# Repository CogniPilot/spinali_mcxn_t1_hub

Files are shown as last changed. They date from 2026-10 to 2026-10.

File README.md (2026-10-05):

# MR-MCXN-T1 Hub

> [!NOTE]
> An MCXN947 based multi-purpose base board with a modular board-to-board connector interface. 
> The base board is supplied with the following features:
> - 3S-12S supply voltage
> - 100BASE-T1 Ethernet
> - 2x CAN
> - IMU (TDK InvenSense ICM-45686)
> - Magnetometer (Bosch BMM350)
> - Barometer (Bosch BMP581)
> - USB
> - 10-pin debug connector (Pixhawk standard)
> - Addressable RGB LED

> [!TIP]
> Possible use-cases for add-on boards:
> Camera, Microphone, Audio, SDIO, Mikrobus, Display, ADC, IO
>
> Please see the associated add-on boards [here](https://github.com/CogniPilot/spinali_mcxn_t1_shields).

MR-MCXN-T1 Top view  |  MR-MCXN-T1 Bottom view
:-------------------------:|:-------------------------:
IMG_8519_cropped | IMG_8513_cropped

> [!NOTE]
> Designed with KiCAD
> 
> All JST-GH connector pinouts follows the [DS-009 Connector Standard](https://github.com/pixhawk/Pixhawk-Standards/blob/master/DS-009%20Pixhawk%20Connector%20Standard.pdf).

> [!NOTE]
> If desiring to contribute please open [all PRs here](https://github.com/CogniPilot/spinali_mcxn_t1_hub/pulls).

## Board overview

All pin data below comes from the KiCad design files in this repository.

Each card shows, per pin, the **function**, the **net name in the schematic** and the **MCU pad**
the signal ends up on. Parts in between, such as the CAN transceivers and the Ethernet PHY, are
shown too. Pin 1 is the square pad.

<!-- overview:top -->
<picture>
  <source media="(prefers-color-scheme: dark)" srcset="images/overview-top-dark.svg">
  MR-MCXN-T1 Hub top view with connector labels
</picture>
<!-- /overview -->

<!-- overview-list:top -->
Bottom side: [J1 VIN + T1](#hub-j1-vin--t1) · [J2 USB](#hub-other-connectors) · [J5 DEBUG](#hub-j5-debug) · [J13 RTC_BAT](#hub-j13-rtc_bat) · [SW1 ISP](#buttons-and-switches).
<!-- /overview-list -->

Bottom side, with the power and Ethernet connector, USB, debug port and the bottom CAN connectors:

<!-- overview:bottom -->
<picture>
  <source media="(prefers-color-scheme: dark)" srcset="images/overview-bottom-dark.svg">
  MR-MCXN-T1 Hub bottom view with connector labels
</picture>
<!-- /overview -->

<!-- overview-list:bottom -->
New in the current revision, bottom right corner (the photo shows the old revision): [J13 RTC_BAT](#hub-j13-rtc_bat).
<!-- /overview-list -->

## Connector index

<!-- index -->
| Ref | Function | Connector | Details |
|---|---|---|---|
| [Hub J1](#hub-j1-vin--t1) VIN + T1 | Battery input 3S to 12S and 100BASE-T1 Ethernet on one cable | Molex Micro-Lock Plus 1x4 (505578-0421), 1.25 mm, side entry |  |
| [Hub J2](#hub-other-connectors) USB | USB 2.0 high-speed device port | USB Type-C receptacle (USB4105-GF-A) | On USB1 of the MCXN947 (high speed). The board is always a USB device (CC pull-downs). VBUS powers the board through load switch U2 when no battery is connected. With SW1 held at power up the boot ROM listens here for ISP programming. |
| [Hub J3](#hub-j3-can0) CAN0 | CAN FD bus 0 (TJA1462), two connectors in parallel | JST-GH 1x4, J3 on the bottom side and J4 on the top side |  |
| [Hub J5](#hub-j5-debug) DEBUG | SWD, JTAG and console, DS-009 debug full layout | JST-SH 1x10 |  |
| [Hub J6](#hub-j6-can1) CAN1 | CAN FD bus 1 (TJA1462), two connectors in parallel | JST-GH 1x4, J6 on the bottom side and J7 on the top side |  |
| [Hub J8](#hub-j8-b2b-power--io) B2B POWER + IO | Add-on board connector 1: power rails and FlexComm, I3C, analog and trace pins | Hirose DF40 50-pin header, 0.4 mm pitch, 3.0 mm stack (DF40TC(3.0)-50DP-0.4V) |  |
| [Hub J9](#hub-j9-b2b-sdhc--io) B2B SDHC + IO | Add-on board connector 2: SDHC or FlexComm 9, SmartDMA or FlexComm 6/7, and more FlexComm pins | Hirose DF40 50-pin header, 0.4 mm pitch, 3.0 mm stack (DF40TC(3.0)-50DP-0.4V) |  |
| [Hub J13](#hub-j13-rtc_bat) RTC_BAT | Backup battery for the RTC | JST-SH 1x2, side entry |  |
| [Hub RGB](#hub-rgb-led-chain) LED CHAIN | Output of the on-board RGB LED, solder pads | Three pads marked CKO, SDO and G next to U14, 5 V logic |  |
<!-- /index -->

## Power, Ethernet and USB

<!-- heading:main/J1 -->
### Hub J1 VIN + T1
<!-- /heading -->

<!-- pinout:main/J1 -->
<picture>
  <source media="(prefers-color-scheme: dark)" srcset="images/main-J1-dark.svg">
  Hub J1 VIN + T1 pinout
</picture>

Pin 1 takes the battery, 3S to 12S (about 9 to 50 V), 10 W budget. An ideal diode (LM74700) blocks reverse polarity, a buck converter makes 5 V from it, and 3.3 V and 1.8 V come from the 5 V rail. The 5 V rail switches on above about 8 V. Pins 2 and 3 are the 100BASE-T1 pair, one twisted pair to the TJA1103 PHY. The PHY is the link slave (R41 fitted); remove R41 to make it the master. The other end of the T1 link must be the master. Mating parts from the schematic: socket 505570-0401, crimp 505572-1100, pre-crimped wires 217500-1125 (black) and 217500-2125 (red).

> [!CAUTION]
> Pin 1 is the only power input besides USB. Keep the battery above 3S, the board does not start below about 8 V.
<!-- /pinout -->

## CAN

<!-- heading:main/J3 -->
### Hub J3 CAN0
<!-- /heading -->

<!-- pinout:main/J3 -->
<picture>
  <source media="(prefers-color-scheme: dark)" srcset="images/main-J3-dark.svg">
  Hub J3 CAN0 pinout
</picture>

J3 (bottom) and J4 (top) carry the same bus, so one cable can come in and another go out. The transceiver runs from 5 V and talks to the chip at 3.3 V. Drive P4_14 (CAN0_STB) low to enable it. The split termination (R27, R28 and C70) is not fitted, so the bus must be terminated elsewhere, or fit the parts if the hub is one end of the bus.

> [!NOTE]
> Pin 1 is not powered. It is only linked between J3 and J4, so a 5 V supply on one cable passes to the other.
<!-- /pinout -->

<!-- heading:main/J6 -->
### Hub J6 CAN1
<!-- /heading -->

<!-- pinout:main/J6 -->
<picture>
  <source media="(prefers-color-scheme: dark)" srcset="images/main-J6-dark.svg">
  Hub J6 CAN1 pinout
</picture>

Same circuit as CAN0. J6 (bottom) and J7 (top) carry the same bus. Drive P4_17 (CAN1_STB) low to enable the transceiver. The split termination (R30, R31 and C75) is not fitted.

> [!NOTE]
> Pin 1 is not powered. It is only linked between J6 and J7, so a 5 V supply on one cable passes to the other.
<!-- /pinout -->

## Debug

<!-- heading:main/J5 -->
### Hub J5 DEBUG
<!-- /heading -->

<!-- pinout:main/J5 -->
<picture>
  <source media="(prefers-color-scheme: dark)" srcset="images/main-J5-dark.svg">
  Hub J5 DEBUG pinout
</picture>

Pin 1 is a 3.3 V reference output for the probe. Pins 2 and 3 are FlexComm 1 as a UART console. Pins 4 to 7 are the SWD and JTAG lines of the MCXN947, pin 8 is a spare GPIO for the probe, pin 9 is the chip reset, pulled up on the board.

> [!WARNING]
> Pin 1 is a reference output, not a supply input. Never power the board from it.
<!-- /pinout -->

## Board-to-board interface

<!-- heading:main/J8 -->
### Hub J8 B2B POWER + IO
<!-- /heading -->

<!-- pinout:main/J8 -->
<picture>
  <source media="(prefers-color-scheme: dark)" srcset="images/main-J8-dark.svg">
  Hub J8 B2B POWER + IO pinout
</picture>

Together with J9 this is the interface for the add-on boards (camera, audio, SDIO, mikroBUS, display, ADC, IO). Odd pins are one row, even pins the other, pin 1 at the cut corner. Limits from the schematic: 300 mA per pin, 5 V rail 1 A, 3.3 V rail 500 mA, 1.8 V rail 200 mA. Pin 11 is the RTC backup supply, shared with J13. The FlexComm blocks (FC2, FC4, FC6) can each be a UART, SPI or I2C. The grey chips list the other functions of each pad.

> [!TIP]
> The add-on board designs are in the spinali_mcxn_t1_shields repository, linked from the main README.
<!-- /pinout -->

<!-- heading:main/J9 -->
### Hub J9 B2B SDHC + IO
<!-- /heading -->

<!-- pinout:main/J9 -->
<picture>
  <source media="(prefers-color-scheme: dark)" srcset="images/main-J9-dark.svg">
  Hub J9 B2B SDHC + IO pinout
</picture>

Second add-on connector. No power pins here, all supplies are on J8. Every signal pin has more than one job, that is the point of this interface. The SDHC0 pins carry an 8-bit SD or eMMC interface, but the same pads are FlexComm 9 (P0 to P6), so an add-on board can use them as one more UART, SPI or I2C instead. The SmartDMA pins are a parallel camera port and double as FlexComm 6 and 7 lines or PWM0 outputs. FC0, FC3 and FC7 can each be a UART, SPI or I2C. Pin 44 is also the IMU sync input. The grey chips list the other functions of each pad.
<!-- /pinout -->

## LED chain and RTC battery

<!-- heading:main/RGB -->
### Hub RGB LED CHAIN
<!-- /heading -->

<!-- pinout:main/RGB -->
<picture>
  <source media="(prefers-color-scheme: dark)" srcset="images/main-RGB-dark.svg">
  Hub RGB LED CHAIN pinout
</picture>

The MCU drives one SK9822 RGB LED (U14, APA102 compatible) from FlexIO pins P0_8 (data) and P0_9 (clock). CKO and SDO are the clock and data outputs of that LED, so more LEDs of the same type can be chained from here. The LED runs from 5 V, so its outputs are 5 V.
<!-- /pinout -->

<!-- heading:main/J13 -->
### Hub J13 RTC_BAT
<!-- /heading -->

<!-- pinout:main/J13 -->
<picture>
  <source media="(prefers-color-scheme: dark)" srcset="images/main-J13-dark.svg">
  Hub J13 RTC_BAT pinout
</picture>

Keeps the real-time clock of the MCXN947 running without main power. Fits the RPi RTC battery (ML2020 with a 2-pin JST-SH plug). The same supply is on J8 pin 11 for the add-on board. The board charges the cell from 3.3 V through D15 and a 75 Ω resistor.

> [!WARNING]
> The board trickle-charges this cell. Use a rechargeable ML2020 type, never a CR2032 or other non-rechargeable cell.
<!-- /pinout -->

<!-- others:main -->
### Hub other connectors

| Ref | Function | Connector | Notes |
|---|---|---|---|
| J2 USB | USB 2.0 high-speed device port | USB Type-C receptacle (USB4105-GF-A) | On USB1 of the MCXN947 (high speed). The board is always a USB device (CC pull-downs). VBUS powers the board through load switch U2 when no battery is connected. With SW1 held at power up the boot ROM listens here for ISP programming. |
<!-- /others -->

## Buttons and switches

<!-- switches -->
| Ref | Board | Function | Type | Notes |
|---|---|---|---|---|
| SW1 ISP | Hub | ISP boot button | Tactile switch, bottom side | Hold it while power comes up to start the boot ROM in ISP mode (P0_6 ISPMODE_N pulled low), for programming over USB or the debug UART. Normal boot otherwise. |
<!-- /switches -->

## On-board devices

How the sensors, the PHY and the LED are wired to the MCXN947. Useful for a device tree or
board file.

| Device | Bus | MCU pins | Notes |
|---|---|---|---|
| ICM-45686 IMU (U9) | SPI on FlexComm 8 | SCK P3_15, MOSI P3_14, MISO P3_16, CS P3_17, INT1 P3_22, FSYNC/INT2 P0_18 | P0_18 is also on J9 pin 44 as IMU sync. |
| BMM350 magnetometer (U10) | I3C0 (or I2C) | SDA P0_20, SCL P0_21, INT P0_19 | Address 0x14. Runs from 1.8 V. |
| BMP581 barometer (U11) | I3C0 (or I2C) | SDA P0_20, SCL P0_21, INT P0_11 | Address 0x47 (SDO pulled up, R48 not fitted). |
| TJA1103 100BASE-T1 PHY (U15) | RMII on ENET0 | TXD0 P1_6, TXD1 P1_7, TXEN P1_5, TXER P1_10, RXD0 P1_14, RXD1 P1_15, RXDV P1_13, RXER P1_12, REFCLK P1_4, MDC P1_20, MDIO P1_21, INT P1_19, RESET P1_11, WAKE P0_31 | Reverse RMII: the PHY supplies the 50 MHz reference clock. PHY address 18. Link slave, because R41 is fitted; remove R41 for master. The two LEDs next to J1 are driven by the PHY GPIO0 and GPIO1. |
| TJA1462 CAN FD transceivers (U12, U13) | FlexCAN0, FlexCAN1 | CAN0 TX P4_13, RX P4_12, STB P4_14; CAN1 TX P4_16, RX P4_15, STB P4_17 | Drive STB low to enable a transceiver. |
| SK9822 RGB LED (U14) | FlexIO | data P0_8, clock P0_9 | APA102 compatible, 5 V. Chain output on the CKO, SDO and G pads. |
| ISP button (SW1) | GPIO | P0_6 | ISPMODE_N, boot ROM ISP mode when held at power up. |

Test pads on the bottom side: CLK is the PHY reference clock (P1_4), GND is ground.

## Notes

- The JST-GH and JST-SH connectors follow the Dronecode
  [DS-009 connector standard](https://github.com/pixhawk/Pixhawk-Standards/blob/master/DS-009%20Pixhawk%20Connector%20Standard.pdf)
  (CAN and debug full), so standard cables fit. The CAN pin 1 is not powered on this board, and
  the CAN termination resistors are not fitted.
- The board runs from the battery on J1 or from USB. 5 V, 3.3 V and 1.8 V for an add-on board
  come from J8.
- The photos show the old revision, marked X-MR-MCXN-T1. The RTC battery connector J13 was
  added in the current revision, in the bottom right corner of the bottom side.

> [!WARNING]
> Never feed power into the 5 V, 3.3 V or 1.8 V pins of J8, or into pin 1 of the debug port. Power the board through J1 or USB only.

## Downloads

This reference as an [A4 PDF](MR-MCXN-T1-Hub-hardware-reference.pdf), and all cards on one
A4 landscape sheet: [cheat sheet PDF](MR-MCXN-T1-Hub-cheatsheet.pdf).

NXP and the NXP logo are registered trademarks of NXP B.V. This document is maintained by the
community and is not an official NXP publication.

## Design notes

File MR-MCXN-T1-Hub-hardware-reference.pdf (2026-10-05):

# MR-MCXN-T1 Hub hardware reference

# Board overview

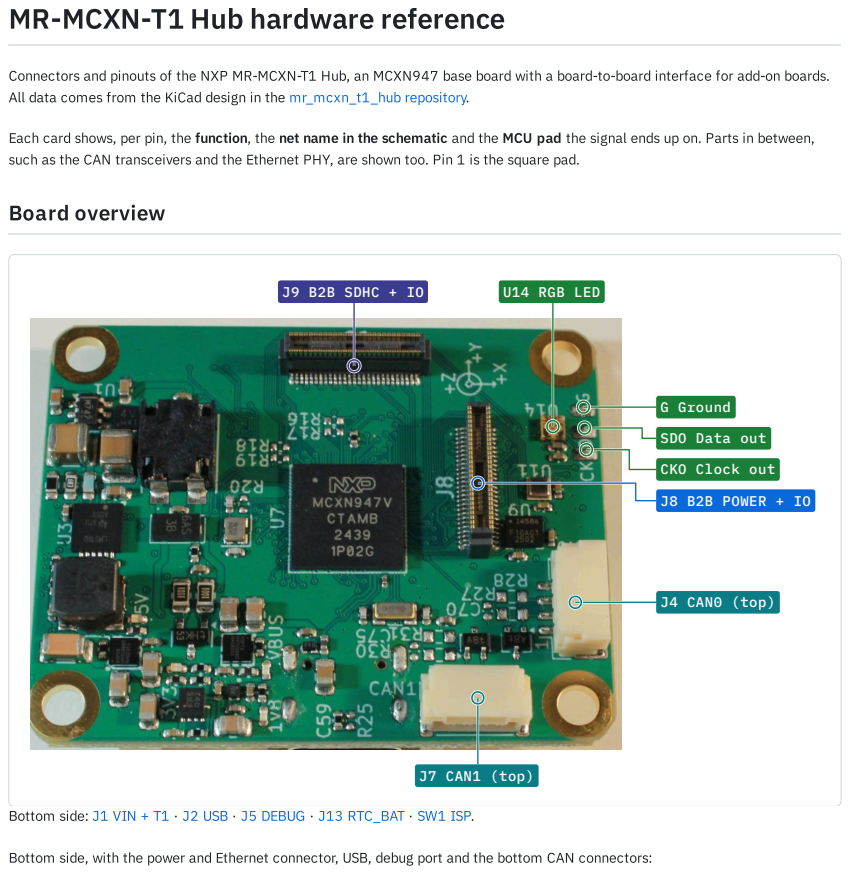
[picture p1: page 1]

Connectors and pinouts of the NXP MR-MCXN-T1 Hub, an MCXN947 base board with a board-to-board interface for add-on boards.

All data comes from the KiCad design in the mr_mcxn_t1_hub repository. (https://github.com/NXP-Robotics/mr_mcxn_t1_hub)

Each card shows, per pin, the function, the net name in the schematic and the MCU pad the signal ends up on. Parts in between,

such as the CAN transceivers and the Ethernet PHY, are shown too. Pin 1 is the square pad.

Bottom side: J1 VIN + T1 · J2 USB · J5 DEBUG · J13 RTC_BAT · SW1 ISP.

Bottom side, with the power and Ethernet connector, USB, debug port and the bottom CAN connectors:

## J3 CAN0 (bottom)

J1 VIN + T1 | J2 USB | J6 CAN1 (bottom)

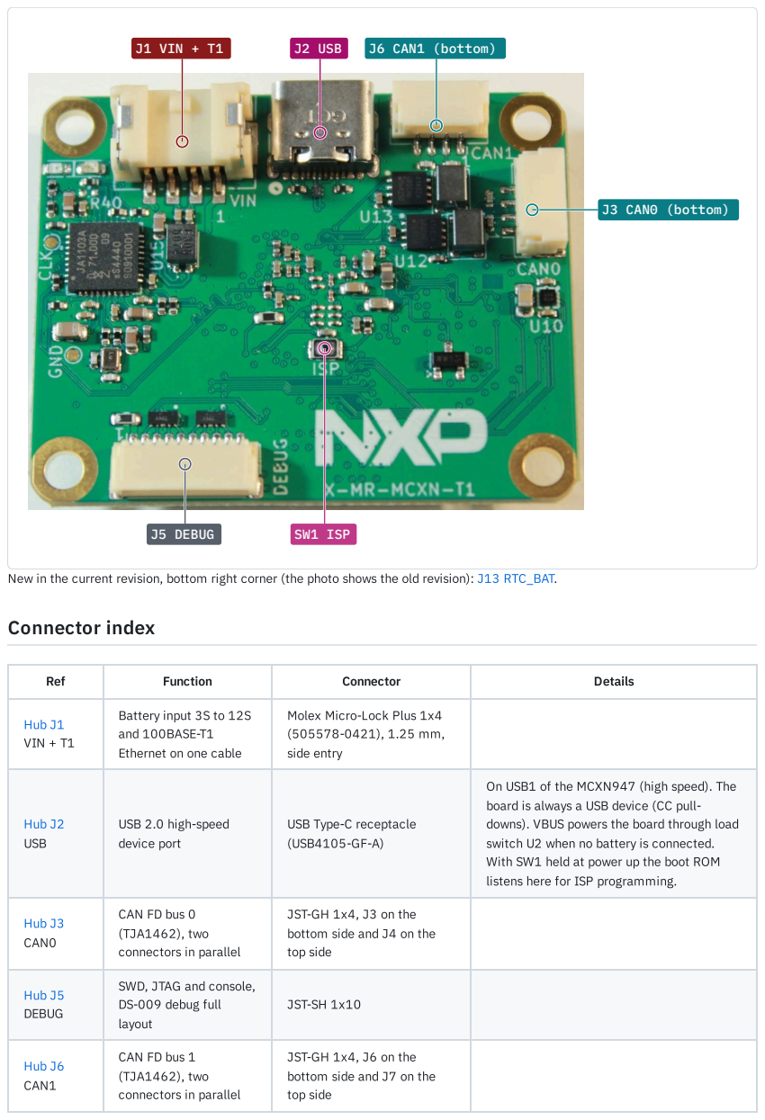
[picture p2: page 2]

New in the current revision, bottom right corner (the photo shows the old revision): J13 RTC_BAT.

Ref | Function | Connector | Details

Hub J1 VIN + T1 | Battery input 3S to 12S and 100BASE-T1 Ethernet on one cable | Molex Micro-Lock Plus 1x4 (505578-0421), 1.25 mm, side entry

Hub J2 USB | USB 2.0 high-speed device port | USB Type-C receptacle (USB4105-GF-A) | On USB1 of the MCXN947 (high speed). The board is always a USB device (CC pull-downs). VBUS powers the board through load switch U2 when no battery is connected. With SW1 held at power up the boot ROM listens here for ISP programming.

Hub J3 CAN0 | CAN FD bus 0 (TJA1462), two connectors in parallel | JST-GH 1x4, J3 on the bottom side and J4 on the top side

Hub J5 DEBUG | SWD, JTAG and console, DS-009 debug full layout | JST-SH 1x10

Hub J6 CAN1 | CAN FD bus 1 (TJA1462), two connectors in parallel | JST-GH 1x4, J6 on the bottom side and J7 on the top side

Ref | Function | Connector | Details
Hub J8 B2B POWER + IO | Add-on board connector 1: power rails and FlexComm, I3C, analog and trace pins | Hirose DF40 50-pin header, 0.4 mm pitch, 3.0 mm stack (DF40TC(3.0)-50DP-0.4V)
Hub J9 B2B SDHC + IO | Add-on board connector 2: SDHC or FlexComm 9, SmartDMA or FlexComm 6/7, and more FlexComm pins | Hirose DF40 50-pin header, 0.4 mm pitch, 3.0 mm stack (DF40TC(3.0)-50DP-0.4V)
Hub J13 RTC_BAT | Backup battery for the RTC | JST-SH 1x2, side entry
Hub RGB LED CHAIN | Output of the on-board RGB LED, solder pads | Three pads marked CKO, SDO and G next to U14, 5 V logic

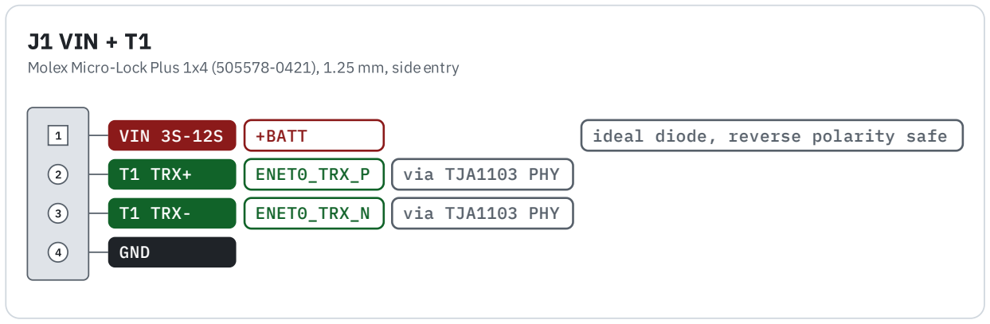
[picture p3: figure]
J1 VIN + T1; T1 TRX+; ENET0_TRX_P; via TJA1103 PHY; T1 TRX-; ENET0_TRX_N; GND

Molex Micro-Lock Plus 1x4 (505578-0421), 1.25 mm, sideentry

1 | VIN 3S-12S | +BATT | ideal diode, reverse polarity safe

Pin 1 takes the battery, 3S to 12S (about 9 to 50 V), 10 W budget. An ideal diode (LM74700) blocks reverse polarity, a buck

converter makes 5 V from it, and 3.3 V and 1.8 V come from the 5 V rail. The 5 V rail switches on above about 8 V. Pins 2 and 3 are

the 100BASE-T1 pair, one twisted pair to the TJA1103 PHY. The PHY is the link slave (R41 fitted); remove R41 to make it the

master. The other end of the T1 link must be the master. Mating parts from the schematic: socket 505570-0401, crimp 505572-

1100, pre-crimped wires 217500-1125 (black) and 217500-2125 (red).

### Caution

Pin 1 is the only power input besides USB. Keep the battery above 3S, the board does not start below about 8 V.

# Power, Ethernet and USB

### Hub J1 VIN + T1

## J3 CAN0

JST-GH 1x4, J3 on the bottom side and J4 on the top side · DS-009 CAN

120 Ω termination: not fitted

TJA1462

CAN FD transceiver

CANH | TXD | CAN0 TX | P4_13
CANL | RXD | CAN0 RX | P4_12
1 | 5V pass-through | NC | J3.1 to J4.1 only
2 | CAN H | CAN0_CONN_P
3 | CAN L | CAN0_CONN_N
4 | GND

J3 (bottom) and J4 (top) carry the same bus, so one cable can come in and another go out. The transceiver runs from 5 V and talks

to the chip at 3.3 V. Drive P4_14 (CAN0_STB) low to enable it. The split termination (R27, R28 and C70) is not fitted, so the bus

must be terminated elsewhere, or fit the parts if the hub is one end of the bus.

### Note

Pin 1 is not powered. It is only linked between J3 and J4, so a 5 V supply on one cable passes to the other.

## J6 CAN1

JST-GH 1x4, J6 on the bottom side and J7 on the top side · DS-009 CAN

120 Ω termination: not fitted

TJA1462

CAN FD transceiver

CANH | TXD | CAN1 TX | P4_16
CANL | RXD | CAN1 RX | P4_15
1 | 5V pass-through | NC | J6.1 to J7.1 only
2 | CAN H | CAN1_CONN_P
3 | CAN L | CAN1_CONN_N
4 | GND

Same circuit as CAN0. J6 (bottom) and J7 (top) carry the same bus. Drive P4_17 (CAN1_STB) low to enable the transceiver. The

split termination (R30, R31 and C75) is not fitted.

### Note

Pin 1 is not powered. It is only linked between J6 and J7, so a 5 V supply on one cable passes to the other.

# CAN

### Hub J3 CAN0

### Hub J6 CAN1

J5 DEBUG

JST-SH 1x10 · DS-009 debug full · 3.3 V logic

1 | VREF 3.3V | +3.3V
2 | UART TX | FC1_P1_UART_TXD | FC1_P1 | CT0_MAT1 | ADC0_B17 | P0_25
3 | UART RX | FC1_P0_UART_RXD | FC1_P0 | CT0_MAT0 | ADC0_B16 | P0_24
4 | SWDIO | DEBUG_TMS_SWDIO | TMS | | | P0_0
5 | SWCLK | DEBUG_TCLK_SWCLK | TCK | | | P0_1
6 | SWO | DEBUG_TDO_SWO | TDO | | | P0_2
7 | TDI | DEBUG_TDI | P0_3 | JTAG only
8 | GPIO | DEBUG_GPIO | FC0_P0 | CT0_MAT2 | | P0_4
9 | nRST | RESET_b | chip reset, active low
10 | GND

Pin 1 is a 3.3 V reference output for the probe. Pins 2 and 3 are FlexComm 1 as a UART console. Pins 4 to 7 are the SWD and JTAG

lines of the MCXN947, pin 8 is a spare GPIO for the probe, pin 9 is the chip reset, pulled up on the board.

### Warning

Pin 1 is a reference output, not a supply input. Never power the board from it.

# Debug

### Hub J5 DEBUG

J8B2B POWER +IO

Hirose DF40 50-pin header, 0.4 mm pitch, 3.0 mm stack (DF40TC(3.0)-50DP-0.4V) · 3.3 V logic

POWER | 5V, 3.3V, RTC backup | POWER | 5V, 3.3V
POWER | 1.8V | I3C | I3C1 SDA, SCL
FLEXCOMM | FC2 | FLEXCOMM | FC4, FC6
ANALOG | ANA_22, ANA_6 | FLEXCOMM | FC6
FLEXIO | D7, D29 | TRACE | DATA2, DATA3
GND | 1
+5V | 5V | 3
+5V | 5V | 5
GND | 7
+3V3 | 3.3V | 9
VDD_BAT | RTC backup | 11
GND | 13
GND | 15
+1V8 | 1.8V | 17
GND | 19
CT_INP16 | FC2_P0 | P4_0 | 21
CT_INP17 | FC2_P1 | P4_1 | 23
GND | 25
CT_INP12 | DAC0_OUT | ADC1_A4 ADC0_A4 | FC2_P2 | P4_2 | 27
CT_INP13 | DAC1_OUT | ADC1_B4 ADC0_B4 | FC2_P3 | P4_3 | 29
GND | 31
CT2_MAT3 | OPAMP2_OUT ADC1_B3 ADC0_B2 ADC0_A2 | FC2_P6 | P4_23 | 33
FLEXIO0_D28 CT2_MAT0 | OPAMP2_INP0 ADC1_A6 | FC2_P4 | P4_20 | 35
GND | 37
OPAMP2_INN | ANA_22 | 39
ADC1_A3 ADC0_A3 | DAC2_OUT | ANA_6 | 41
GND | 43
CT_INP3 ADC0_A15 | FC1_P3 | FLEXIO0_D7 | P0_23 | 45
SAI1_RXD0 PWM1_B3 CT2_MAT3 | FC6_P1 | FC8_P5 | FLEXIO0_D29 | P3_21 | 47
GND | 49
2 | GND
4 | 5V | +5V
6 | 5V | +5V
8 | GND
10 | 3.3V | +3V3
12 | GND
14 | P1_8 | I3C1_SDA/FC4_P0 | FC5_P4 | ADC1_A8 CT_INP8 FLEXIO0_D16
16 | P1_9 | I3C1_SCL/FC4_P1 | FC5_P5 | ADC1_A9 CT_INP9 FLEXIO0_D17
18 | GND
20 | P1_22 | FC4_P2 | FC5_P6 | ADC1_A22 | CT_INP14 | FLEXIO0_D30 SCT0_OUT4
22 | P1_23 | FC4_P3 | ADC1_A23 | CT_INP15 | FLEXIO0_D31 SCT0_OUT5
24 | GND
26 | P3_1 | FC6_P0 | FC7_P6 | CT_INP17 | PWM0_B0 FLEXIO0_D9
28 | P3_6 | FC6_P1 | CT4_MAT2 | PWM0_A1 FLEXIO0_D14 SAI1_MCLK
30 | GND
32 | P3_10 | FC6_P2 | FC7_P4 | CT1_MAT0 | PWM0_A3 FLEXIO0_D18 SAI0_TXD0
34 | P3_11 | FC6_P3 | FC7_P5 | CT1_MAT1 | PWM0_B3 FLEXIO0_D19 SAI0_RXD0
36 | GND
38 | P3_18 | FC6_P6 | CT2_MAT0 | PWM1_X0 FLEXIO0_D26 SAI1_RX_BCLK
40 | P3_13 | FC6_P5 | FC7_P5 | CT1_MAT3 | PWM1_B0 FLEXIO0_D21 SAI0_TXD1
42 | GND
44 | P2_10 | TRACE_DATA2 | PWM1_X2 FLEXIO0_D18 SAI1_RXD1 SCT0_IN4
46 | P2_11 | TRACE_DATA3 | PWM1_X3 FLEXIO0_D19 SAI1_TXD1 SCT0_IN5
48 | NC
50 | GND

Pin 1 is at the cut corner. Odd pins are one row, even pins the other row, face to face.

Dark pads are GND. Bands only group the rows, the pin order is the real order.

Grey chips: other functions of the same pad.

Together with J9 this is the interface for the add-on boards (camera, audio, SDIO, mikroBUS, display, ADC, IO). Odd pins are one row,

even pins the other, pin 1 at the cut corner. Limits from the schematic: 300 mA per pin, 5 V rail 1 A, 3.3 V rail 500 mA, 1.8 V rail

200 mA. Pin 11 is the RTC backup supply, shared with J13. The FlexComm blocks (FC2, FC4, FC6) can each be a UART, SPI or I2C.

The grey chips list the other functions of each pad.

### Tip

The add-on board designs are in the spinali_mcxn_t1_shields repository, linked from the main README.

# Board-to-board interface

### Hub J8 B2B POWER + IO

J9 B2B SDHC + IO

HiroseDF40 50-pin header, 0.4 mmpitch, 3.0 mmstack(DF40TC(3.0)-50DP-0.4V)· 3.3 V logic

SDHC OR FLEXCOMM 9 | CMD, CLK, D0, D1=FC9P2, P0, P1, P3 | SMARTDMA OR FLEXCOMM | PIO0=FC7P3, PIO7toPIO9=FC6P6, P4, P5
SDHC OR FLEXCOMM 9 | D2, D3, D5=FC9P5, P4, P6 | FLEXCOMM | FC3P0toP3, P6
FLEXCOMM | FC7P0toP3 | FLEXCOMM | FC3P4, P5andFC0P0, P1
FLEXCOMM | FC7P6, P4 | FLEXCOMM | FC0P2(IMU sync), P3, P6
| | | | | | GND | 1
SCT0_OUT3 | SAI0_TXD1 | FLEXIO0_D13 | PWM1_B1 | FC9_P2 | SDHC0_CMD | P2_5 | 3
SCT0_OUT2 | SAI0_RXD1 | FLEXIO0_D12 | PWM1_A1 | FC9_P0 | SDHC0_CLK | P2_4 | 5
| | | | | | GND | 7
SCT0_OUT1 | SAI0_RXD0 | FLEXIO0_D11 | PWM1_B2 | FC9_P1 | SDHC0_D0 | P2_3 | 9
SCT0_OUT0 | SAI0_TXD0 | FLEXIO0_D10 | PWM1_A2 | FC9_P3 | SDHC0_D1 | P2_2 | 11
| | | | | | GND | 13
SCT0_OUT5 | SAI0_TX_FS | FLEXIO0_D15 | PWM1_B0 | FC9_P5 | SDHC0_D2 | P2_7 | 15
SCT0_OUT4 | SAI0_TX_BCLK | FLEXIO0_D14 | PWM1_A0 | FC9_P4 | SDHC0_D3 | P2_6 | 17
GND | 19
SCT0_IN1 | TRACE_CLK | SAI0_RX_FS | FLEXIO0_D9 | PWM1_B3 | SDHC0_D4 | P2_1 | 21
SCT0_IN0 | SAI0_RX_BCLK | FLEXIO0_D8 | PWM1_A3 | FC9_P6 | SDHC0_D5 | P2_0 | 23
GND | 25
SCT0_IN3 | TRACE_DATA1 | SAI1_RXD0 | FLEXIO0_D17 | PWM1_X1 | SDHC0_D6 | P2_9 | 27
SCT0_IN2 | TRACE_DATA0 | SAI1_TXD0 | FLEXIO0_D16 | PWM1_X0 | SDHC0_D7 | P2_8 | 29
GND | 31
FLEXIO0_D10 | PWM0_X0 | CT4_MAT0 | FC7_P0 | P3_2 | 33
FLEXIO0_D11 | PWM0_X1 | CT4_MAT1 | FC7_P1 | P3_3 | 35
GND | 37
FLEXIO0_D12 | PWM0_X2 | CT_INP18 | FC7_P2 | P3_4 | 39
FLEXIO0_D13 | PWM0_X3 | CT_INP19 | FC7_P3 | P3_5 | 41
GND | 43
SAI1_RX_FS | FLEXIO0_D27 | PWM1_X1 | CT2_MAT1 | FC7_P6 | P3_19 | 45
SAI0_RXD1 | FLEXIO0_D20 | PWM1_A0 | CT1_MAT2 | FC6_P4 | FC7_P4 | P3_12 | 47
GND | 49
2 | GND
4 | P3_0 | SmartDMA_PIO0 | FC7_P3 | CT_INP16 | PWM0_A0 | FLEXIO0_D8
6 | P3_7 | SmartDMA_PIO7 | FC6_P6 | FC7_P1 | CT4_MAT3 | PWM0_B1 | FLEXIO0_D15
8 | GND
10 | P3_8 | SmartDMA_PIO8 | FC6_P4 | FC7_P0 | CT_INP4 | PWM0_A2 | FLEXIO0_D16
12 | P3_9 | SmartDMA_PIO9 | FC6_P5 | FC7_P2 | CT_INP5 | PWM0_B2 | FLEXIO0_D17
14 | GND
16 | P1_0 | FC3_P0 | FC4_P4 | ADC0_A16 | CT_INP4 | FLEXIO0_D8 | SAI1_TX_BCLK
18 | P1_1 | FC3_P1 | FC4_P5 | ADC0_A17 | CT_INP5 | FLEXIO0_D9 | SAI1_TX_FS
20 | GND
22 | P1_2 | FC3_P2 | FC4_P6 | CAN0_TXD | ADC0_A18 | CT1_MAT0
24 | P1_3 | FC3_P3 | CAN0_RXD | ADC0_A19 | CT1_MAT1 | FLEXIO0_D11
26 | GND
28 | P1_18 | FC3_P6 | FC5_P2 | CAN0_TXD | ADC1_A18 | CT3_MAT0
30 | GND
32 | P1_16 | FC3_P4 | FC5_P0 | I3C1_SDA | ADC1_A16 | CT_INP12
34 | P1_17 | FC3_P5 | FC5_P1 | I3C1_SCL | ADC1_A17 | CT_INP13
36 | GND
38 | P0_16 | FC0_P0 | I3C0_SDA | ADC0_A8 | CT0_MAT0 | FLEXIO0_D0 | TSI0_CH11
40 | P0_17 | FC0_P1 | I3C0_SCL | ADC0_A9 | CT0_MAT1 | FLEXIO0_D1 | TSI0_CH12
42 | GND
44 | P0_18 | FC0_P2/IMU_SYNC | ADC0_A10 | CT0_MAT2 | FLEXIO0_D2 | TSI0_CH13
46 | P0_7 | FC0_P3 | CT_INP3
48 | P0_22 | FC0_P6 | FC1_P2 | ADC0_A14 | CT_INP2 | FLEXIO0_D6
50 | GND

Pin 1 is at the cut corner. Odd pins are one row, even pins the other row, face to face.

Dark pads are GND. Bands only group the rows, the pin order is the real order.

Grey chips: other functions of the same pad.

Second add-on connector. No power pins here, all supplies are on J8. Every signal pin has more than one job, that is the point of this

interface. The SDHC0 pins carry an 8-bit SD or eMMC interface, but the same pads are FlexComm 9 (P0 to P6), so an add-on board

can use them as one more UART, SPI or I2C instead. The SmartDMA pins are a parallel camera port and double as FlexComm 6 and

7 lines or PWM0 outputs. FC0, FC3 and FC7 can each be a UART, SPI or I2C. Pin 44 is also the IMU sync input. The grey chips list

the other functions of each pad.

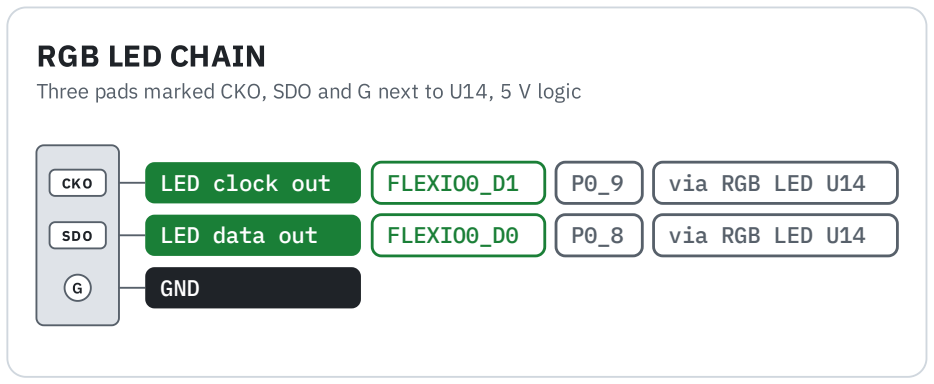
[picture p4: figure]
RGB LED CHAIN; GND

Three pads marked CKO, SDO and G next to U14, 5 V logic

CKO | LED clock out | FLEXIO0_D1 | P0_9 | via RGB LED U14
SDO | LED data out | FLEXIO0_D0 | P0_8 | via RGB LED U14

The MCU drives one SK9822 RGB LED (U14, APA102 compatible) from FlexIO pins P0_8 (data) and P0_9 (clock). CKO and SDO

are the clock and data outputs of that LED, so more LEDs of the same type can be chained from here. The LED runs from 5 V, so its

outputs are 5 V.

### Hub J9 B2B SDHC + IO

# LED chain and RTC battery

### Hub RGB LED CHAIN

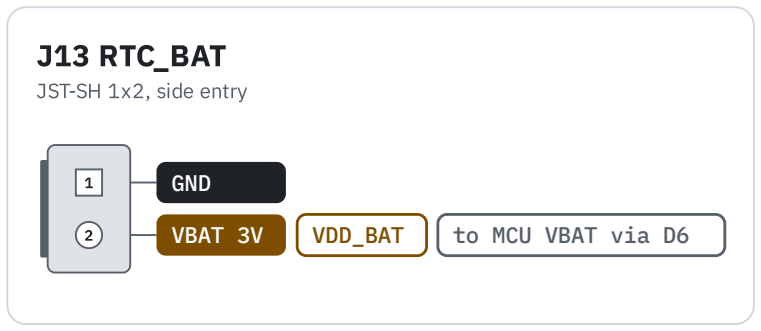
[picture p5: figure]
J13 RTC_BAT; JST-SH 1x2, side entry; GND; VBAT 3V; VDD_BAT; to MCU VBAT via D6

Keeps the real-time clock of the MCXN947 running without main power. Fits the RPi RTC battery (ML2020 with a 2-pin JST-SH

plug). The same supply is on J8 pin 11 for the add-on board. The board charges the cell from 3.3 V through D15 and a 75 Ω resistor.

### Warning

The board trickle-charges this cell. Use a rechargeable ML2020 type, never a CR2032 or other non-rechargeable cell.

Ref | Function | Connector | Notes
J2 USB | USB 2.0 high-speed device port | USB Type-C receptacle (USB4105-GF-A) | On USB1 of the MCXN947 (high speed). The board is always a USB device (CC pull-downs). VBUS powers the board through load switch U2 when no battery is connected. With SW1 held at power up the boot ROM listens here for ISP programming.
Ref | Board | Function | Type | Notes
SW1 ISP | Hub | ISP boot button | Tactile switch, bottom side | Hold it while power comes up to start the boot ROM in ISP mode (P0_6 ISPMODE_N pulled low), for programming over USB or the debug UART. Normal boot otherwise.

How the sensors, the PHY and the LED are wired to the MCXN947. Useful for a device tree or board file.

Device | Bus | MCU pins | Notes
ICM-45686 IMU (U9) | SPI on FlexComm 8 | SCK P3_15, MOSI P3_14, MISO P3_16, CS P3_17, INT1 P3_22, FSYNC/INT2 P0_18 | P0_18 is also on J9 pin 44 as IMU sync.
BMM350 magnetometer (U10) | I3C0 (or I2C) | SDA P0_20, SCL P0_21, INT P0_19 | Address 0x14. Runs from 1.8 V.
BMP581 barometer (U11) | I3C0 (or I2C) | SDA P0_20, SCL P0_21, INT P0_11 | Address 0x47 (SDO pulled up, R48 not fitted).

### Hub J13 RTC_BAT

### Hub other connectors

# Buttons and switches

# On-board devices

Device | Bus | MCU pins | Notes
TJA1103 100BASE-T1 PHY (U15) | RMII on ENET0 | TXD0 P1_6, TXD1 P1_7, TXEN P1_5, TXER P1_10, RXD0 P1_14, RXD1 P1_15, RXDV P1_13, RXER P1_12, REFCLK P1_4, MDC P1_20, MDIO P1_21, INT P1_19, RESET P1_11, WAKE P0_31 | Reverse RMII: the PHY supplies the 50 MHz reference clock. PHY address 18. Link slave, because R41 is fitted; remove R41 for master. The two LEDs next to J1 are driven by the PHY GPIO0 and GPIO1.
TJA1462 CAN FD transceivers (U12, U13) | FlexCAN0, FlexCAN1 | CAN0 TX P4_13, RX P4_12, STB P4_14; CAN1 TX P4_16, RX P4_15, STB P4_17 | Drive STB low to enable a transceiver.
SK9822 RGB LED (U14) | FlexIO | data P0_8, clock P0_9 | APA102 compatible, 5 V. Chain output on the CKO, SDO and G pads.
ISP button (SW1) | GPIO | P0_6 | ISPMODE_N, boot ROM ISP mode when held at power up.

Test pads on the bottom side: CLK is the PHY reference clock (P1_4), GND is ground.

The JST-GH and JST-SH connectors follow the Dronecode DS-009 connector standard (https://github.com/pixhawk/Pixhawk-Standards/blob/master/DS-009%20Pixhawk%20Connector%20Standard.pdf) (CAN and debug full), so standard cables

fit. The CAN pin 1 is not powered on this board, and the CAN termination resistors are not fitted.

The board runs from the battery on J1 or from USB. 5 V, 3.3 V and 1.8 V for an add-on board come from J8.

The photos show the old revision, marked X-MR-MCXN-T1. The RTC battery connector J13 was added in the current revision, in

the bottom right corner of the bottom side.

### Warning

Never feed power into the 5 V, 3.3 V or 1.8 V pins of J8, or into pin 1 of the debug port. Power the board through J1 or USB

only.

This reference as an A4 PDF, (http://127.0.0.1:39639/MR-MCXN-T1-Hub-hardware-reference.pdf) and all cards on one A4 landscape sheet: cheat sheet PDF. (http://127.0.0.1:39639/MR-MCXN-T1-Hub-cheatsheet.pdf)

NXP and the NXP logo are registered trademarks of NXP B.V. This document is maintained by the community and is not an official

NXP publication.

# Notes

# Downloads

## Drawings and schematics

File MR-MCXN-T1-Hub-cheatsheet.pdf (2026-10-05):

MR-MCXN-T1 Hub PINOUT CHEAT SHEET | MR-MCXN-T1 Hub | SHEET 1 / 2

# J5 DEBUG

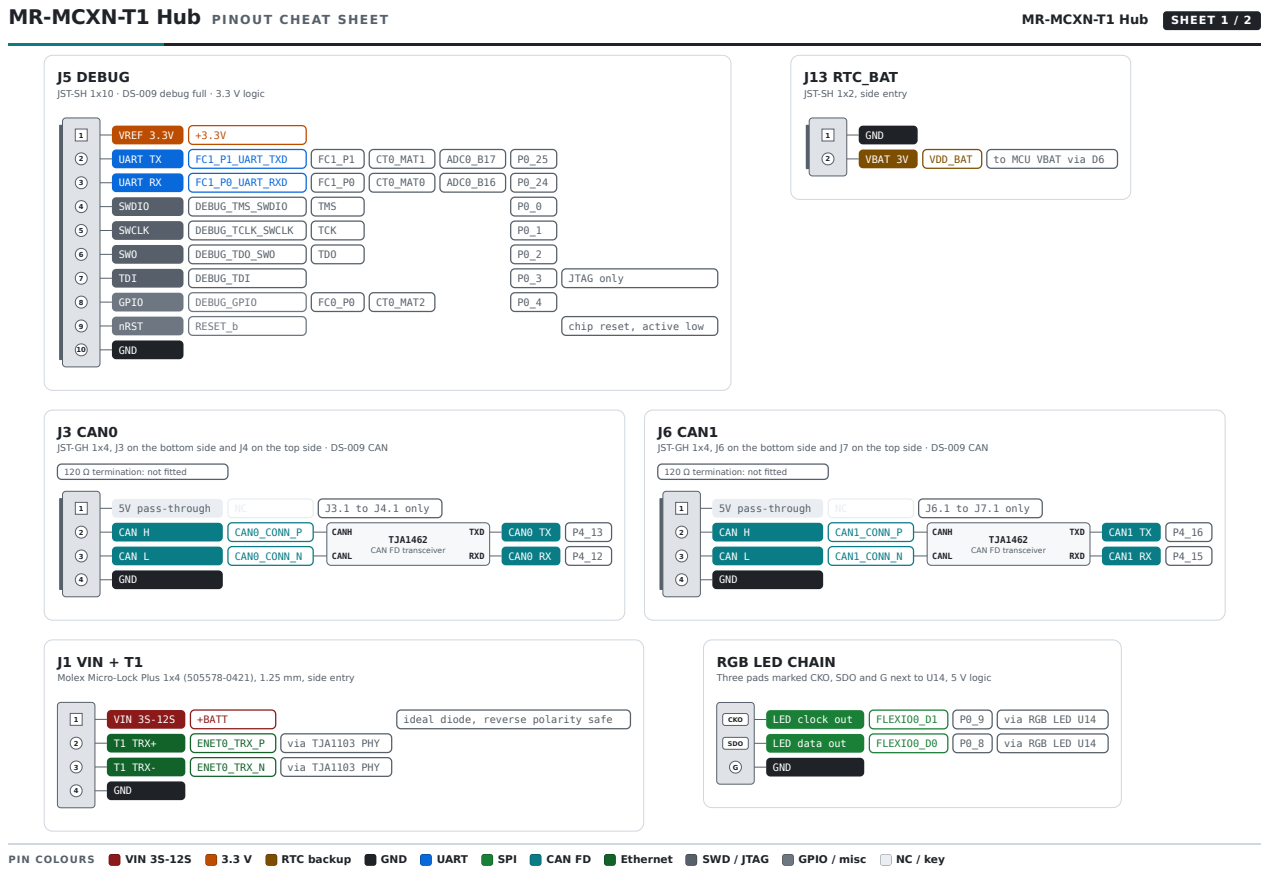
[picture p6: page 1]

J13 RTC_BAT
JST-SH 1x2, side entry

JST-SH 1x10 · DS-009 debug full · 3.3 V logic

J3 CAN0
JST-GH 1x4, J3 on the bottom side and J4 on the top side · DS-009 CAN

J6 CAN1
JST-GH 1x4, J6 on the bottom side and J7 on the top side · DS-009 CAN

J1 VIN + T1
Molex Micro-Lock Plus 1x4 (505578-0421), 1.25 mm, side entry

RGB LED CHAIN
Three pads marked CKO, SDO and G next to U14, 5 V logic

MR-MCXN-T1 Hub PINOUT CHEAT SHEET | Board-to-board interface | SHEET 2 / 2

## J8 B2B POWER + IO

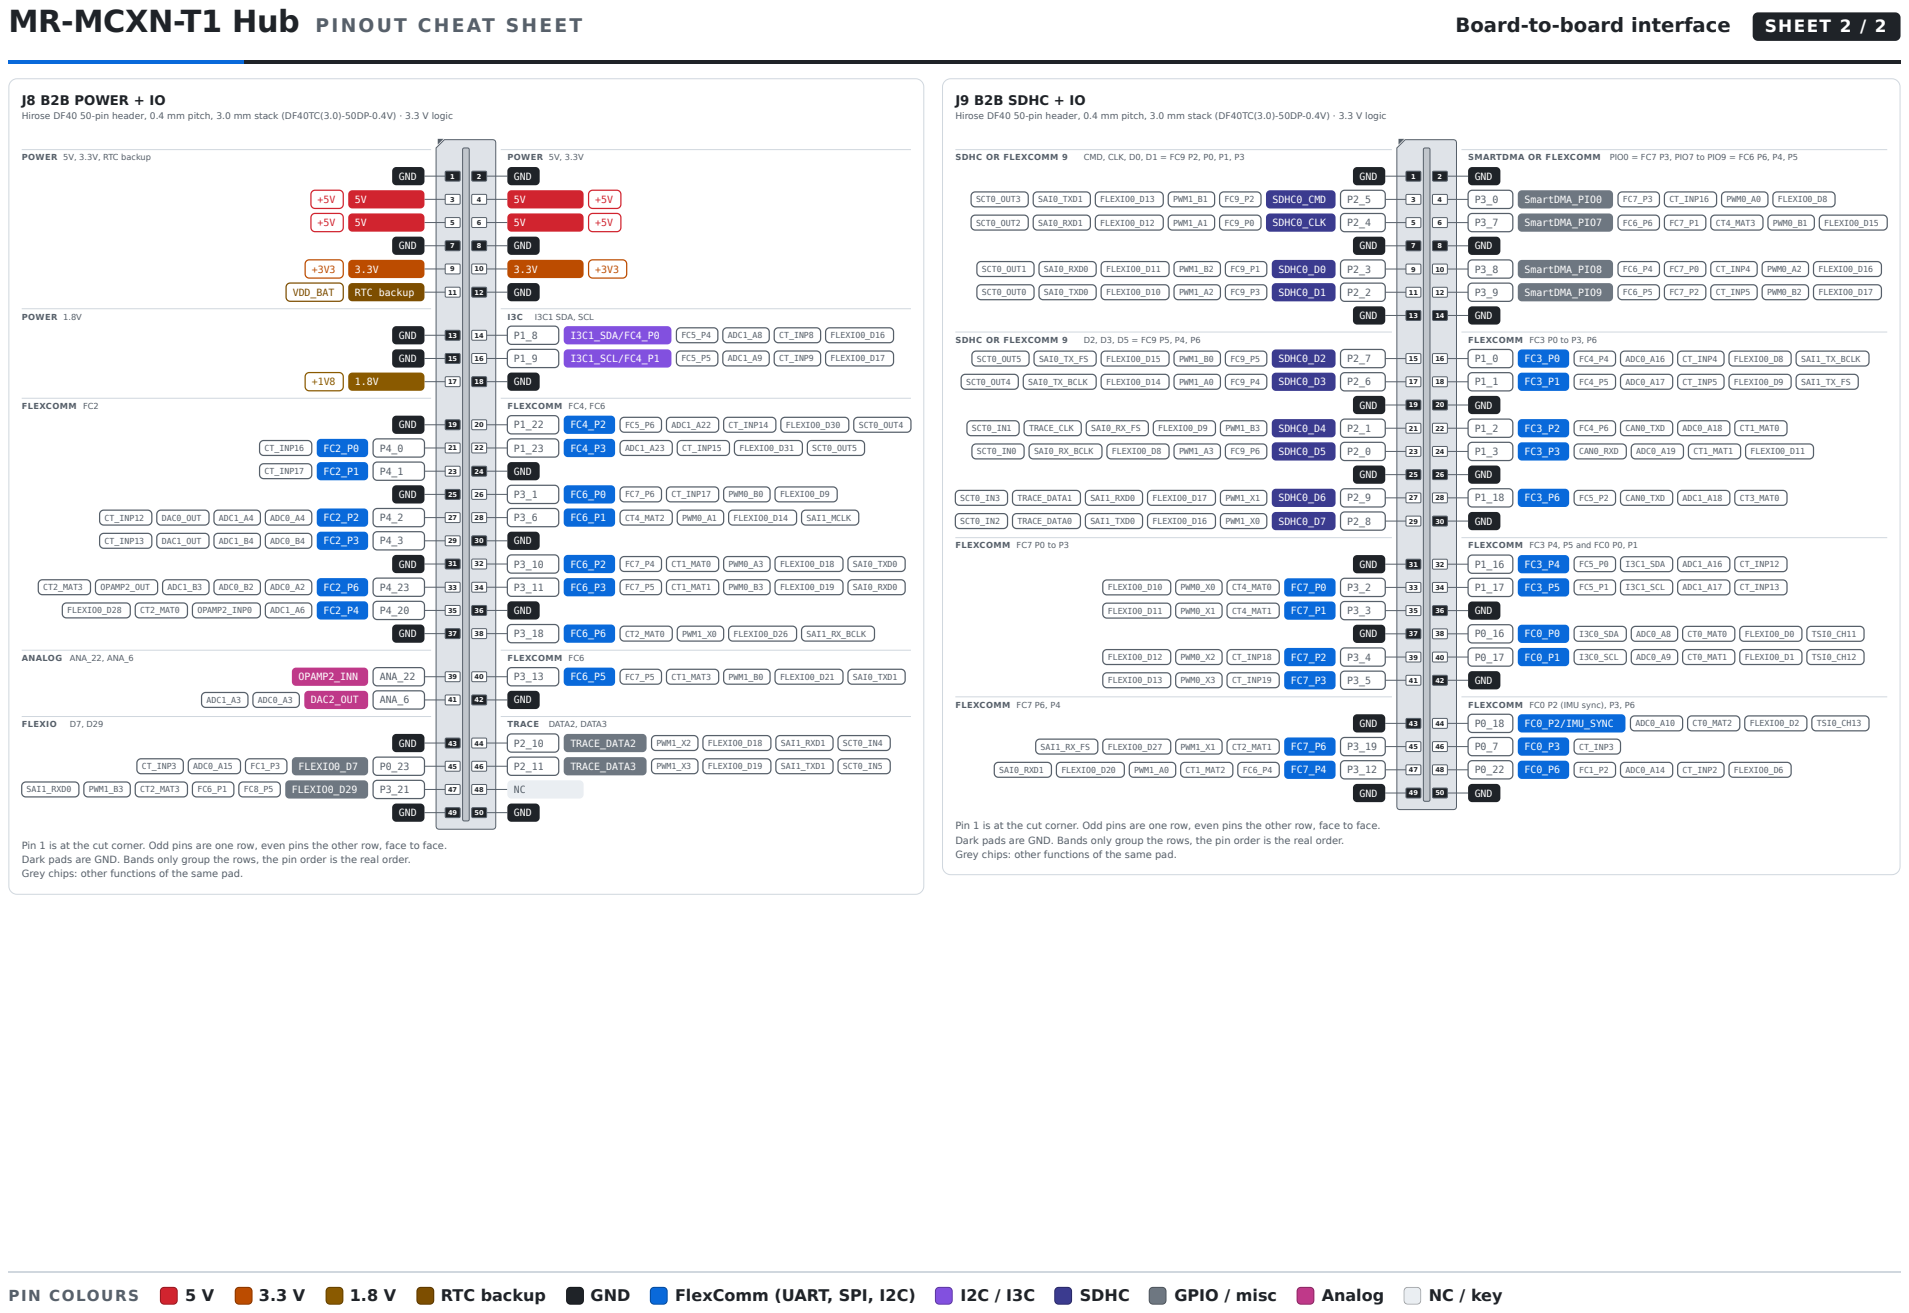
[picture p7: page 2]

J9 B2B SDHC + IO
Hirose DF40 50-pin header, 0.4 mm pitch, 3.0 mm stack (DF40TC(3.0)-50DP-0.4V) · 3.3 V logic

Pin 1 is at the cut corner. Odd pins are one row, even pins the other row, face to face.
Dark pads are GND. Bands only group the rows, the pin order is the real order.
Grey chips: other functions of the same pad.

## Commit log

2025-03-12 Added kicad files
    - Added schematic sheets for each part of the system. Added the parts that need to be in each schematic sheet.
    - Made power supply schematic
    - Added schematic around CAN and T1 ethernet transceivers.
    [communication.kicad_sch, mcu_io_1.kicad_sch, mcu_io_2.kicad_sch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]
2025-03-17 Updated schematics and BOM.
    - Finished power supply schematics
    - Added power schematic around MCXN
    - Assigned MCXN pins
    - Created board-to-board schematic and assigned pins to DF40T board-to-board connector
    - Added correct sensors, finished sensor schematic
    - Updated parts in communication schematic
    - Added all part numbers etc in parts parameters
    [board-to-board.kicad_sch, communication.kicad_sch, mcu_io_1.kicad_sch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]
2025-03-18 Finished schematic design for first review
    Finished schematic design for first review.
    [communication.kicad_sch, ethernet_phy.kicad_sch, mcu_io_1.kicad_sch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]
2025-03-21 Updated schematic and started on layout
    - Implemented schematic changes after feedback:
    - BMM350 VDD is 1.8V
    - Replaced net labels with global labels for page references
    - Added 1uF cap to SK9822-EC20
    - Added rev-RMII configuration for TJA1103 and DNP resistor to put it in slave mode
    - Added TJA1103 PHY address info
    - Changed decoupling caps for MCXN to smallest possible packages
    - Added traces and vias at MCXN according to guidelines
    [board-to-board.kicad_sch, communication.kicad_sch, ethernet_phy.kicad_sch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]
2025-03-21 Updated PCB layout
    - Placed decoupling caps at MCXN with traces.
    - Grouped parts of schematic.
    - Started positioning Power components
    [communication.kicad_sch, mcu_usb_power.kicad_sch, spinali_mcxn_t1_sensor_hub.kicad_pcb]
2025-03-28 Updated schematic after feedback from Jari
    - Finished schematic after feedback from Jari. It is at a finished state, can be reviewed by whole team now.
    - Layouted MCXN with decoupling caps.
    - Layouted Base100-T1 ethernet phy.
    - Layouted the power supply a bit.
    [board-to-board.kicad_sch, communication.kicad_sch, ethernet_phy.kicad_sch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]
2025-04-01 Finished schematic. Completed power and ENET phy layout.
    Layouted power supply and ethernet phy around input connector.
    [board-to-board.kicad_sch, communication.kicad_sch, ethernet_phy.kicad_sch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]
2025-04-01 Updated layout
    Made layout around CANBUS and USB-C.
    [spinali_mcxn_t1_sensor_hub.kicad_pcb]
2025-04-02 Updated PCB layout
    Positioned MCXN947.
    [spinali_mcxn_t1_sensor_hub.kicad_pcb]
2025-04-02 Updated PCB layout
    Positioned MCXN. Routed ENET phy and CAN phy to MCXN.
    [spinali_mcxn_t1_sensor_hub.kicad_pcb]
2025-04-03 Updated PCB layout
    Updated wiring to MCXN. Wired part of signals to board-to-board.
    [spinali_mcxn_t1_sensor_hub.kicad_pcb]
2025-04-04 Updated PCB layout
    Routed all traces on the board.
    [spinali_mcxn_t1_sensor_hub.kicad_pcb]
2025-04-07 Updated PCB layout
    Implemented feedback:
    - Placed ENET LEDs next to each other
    - Added solder pads to output of RGB LED
    - Made hole to hole distance in X-axis to 30.5mm
    - Placed IMU a bit closer to the middle to still comply to the design rules by TDK.
    [communication.kicad_sch, mcu_usb_power.kicad_sch, sensors.kicad_sch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]
2025-04-09 Finalized layout
    - Added extra GND vias where needed.
    - Adjusted board size.
    - Added silkscreen where needed.
    - Verified DRC.
    [spinali_mcxn_t1_sensor_hub.kicad_pcb]
2025-04-11 Updated PCB layout
    - Repositioned board-to-board connectors and holes slightly so distances are easy to work with.
    - Improved routing of some traces.
    - Verified layout with DRC.
    [spinali_mcxn_t1_sensor_hub.kicad_pcb]
2025-04-11 Updated PCB layout
    - Added NXP logo and formal board name placeholder.
    [spinali_mcxn_t1_sensor_hub.kicad_pcb]
2025-04-11 Updated layout
    Added formal board-name in silkscreen.
    [spinali_mcxn_t1_sensor_hub.kicad_pcb]
2025-04-11 Updated layout
    Made edge cut dimensions easy to work with values.
    [spinali_mcxn_t1_sensor_hub.kicad_pcb]
2025-04-16 Update layout
    - Length matched MII RX and TX.
    - Made clearance between USB D+ and D- traces constant.
    - Improved traces for 32kHz crystal.
    [spinali_mcxn_t1_sensor_hub.kicad_pcb]
2025-04-16 Updated layout and BOM
    - Rounded corners of PCB
    - Updated board-to-board MFPN to correct one.
    [board-to-board.kicad_sch, communication.kicad_sch, ethernet_phy.kicad_sch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]
2025-04-24 Updated PCB layout
    - Changed North vector symbol on silk to an XYZ axis symbol.
    - Flipped magnetometer to bottom side to have orientation match the IMU.
    [spinali_mcxn_t1_sensor_hub.kicad_pcb]
2025-04-24 Updated layout and BOM
    - Flipped Magnetometer so it is aligned with the axis of the IMU.
    - Updated BOM so all parts can be sourced from DigiKey. Also added a row for JLCPCB part numbers if applicable.
    - Replaced ISP button with the NanoT160AS. Added "ISP" in silkscreen at that button.
    [board-to-board.kicad_sch, communication.kicad_sch, ethernet_phy.kicad_sch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]
2025-05-23 Updated PCB layout
    Updated all vias to have an annular ring always on the top and bottom layer. This was needed for Vekatech for production.
    [mcu_usb_power.kicad_sch, spinali_mcxn_t1_sensor_hub.kicad_pcb]
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2025-09-02 Patched schematic and board layout
    - Replaced choke in series with Vbus with 2A choke.
    - Fixed interface to the BMP581 barometer.
    - Added schematic fixes to the layout.
    - Completed DRC.
    - Created production folder with Gerber, BOM, positions and schematic.
    [board-to-board.kicad_sch, bom_mcxn_t1.csv, communication.kicad_sch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]
2025-09-24 Patched 1V8 indicator LED circuit
    Added transistor circuit so 1V8 indicator LED goes on when 1V8 power is active.
    [bom_mcxn_t1.csv, power_supplies.kicad_sch, spinali_mcxn_t1_hub.kicad_pcb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]
2025-11-24 Add note about Molex connector
    Add mating connector and jumper wire comments
    [power_supplies.kicad_sch]
2026-07-24 Updated MR-MCXN-T1 hub to production version X1
    - Populated I3C 10k pull-up resistors, R16, R17, R18 and R19
    - Updated page information and revision number to X1
    [board-to-board.kicad_sch, communication.kicad_sch, ethernet_phy.kicad_sch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]
2026-07-24 Delete kicad/production directory
    Removed production directory as this causes confusion. Production files can be found at the Releases.
    [bom_mcxn_t1.csv, spinali_mcxn_t1_hub.step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]
2026-07-27 Added RTC battery connector
    - Added RTC battery connector JST-SH 2-pin.
    - re-routed layout to make space for the new battery connector.
    [power_supplies.kicad_sch, spinali_mcxn_t1_hub.kicad_pcb]
2026-07-27 Updated layout
    - Rotated RTC battery connector.
    - Improved CAN differential pairs routing.
    [board-to-board.kicad_sch, communication.kicad_sch, ethernet_phy.kicad_sch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]
2026-07-27 Fixed RTC battery connection
    - Fixed polarity of RTC battery connector so it is correct.
    [power_supplies.kicad_sch, spinali_mcxn_t1_hub.kicad_pcb]
2026-07-28 Improved layout
    - Improved CAN impedance routing
    - Improved overall layout and silkscreen
    - Finished DRC
    [spinali_mcxn_t1_hub.kicad_pcb]
2026-08-24 MR-MCXN-T1 Rev A Production
    - Added Rev A in schematic and layout
    - Updated footprints
    - Succesfull DRC
    [board-to-board.kicad_sch, communication.kicad_sch, ethernet_phy.kicad_sch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]
2026-08-27 Fixed silkscreen
    - Swapped silkscreen of C59 and R25.
    [spinali_mcxn_t1_hub.kicad_pcb]
